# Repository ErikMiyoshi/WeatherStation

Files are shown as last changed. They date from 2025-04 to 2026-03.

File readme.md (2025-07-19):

# 💡 Multi-Domain Learning Project: Hardware, Firmware & Software

Welcome to this project that combines **hardware design**, **embedded firmware**, and **application-level software**. The project is a portable weather station that gets temperature, humidity, pressure and show on a dashboard.

## 🧭 Project Goal

This is a personal project for me to learning all aspects of an embedded system project that involves:

- 🔧 **Hardware**: Circuit design, schematics, and PCB development
- 🧠 **Firmware**: Embedded code for microcontrollers, in this case ESP32
- 💻 **Software**: Applications that interact with the device, including dashboards and data logging

The objective is to **understand how these layers connect**, and how to manage a multidisciplinary project effectively.

---

## 🗂 Repository Structure

WeatherStation/
├── HW/ # Schematics, PCB design files (KiCad, etc.)
├── FW/ # Embedded C/C++ code (e.g., ESP-IDF)
├── SW/ # Python, Flask, GUI application (e.g., dashboard)
├── docs/ # Documentation, diagrams, and learning notes
├── LICENSE
└── README.md

---

## 📌 What I'm learning

- Designing a hardware system using open-source tools
- Writing low-level embedded firmware to read sensors and communicate
- Creating software tools to visualize and log the collected data
- Managing a complete project in a clean and modular way

---

## 🛠 Tech Stack

| Layer | Technology |
|---|---|
| Hardware | KiCad, breadboards, ESP32, sensors|
| Firmware | C, C++, ESP-IDF, MQTT |
| Software | Python, Flask, MQTT, Chart.js |
| Tools | Git, VSCode, KiCad, esp-idf |

---

## 🤝 Contributing

This is a learning project. Contributions are welcome! Feel free to open issues, suggest improvements, or ask questions. The goal is to learn collaboratively.

I'm not the best at programming and this project is also for me to improve my ability in writing code.

## 📄 License

This project is licensed under the MIT License. See LICENSE for details.

## 🙋‍♂️ Author
Created by Erik as a personal journey to explore full-stack embedded systems.

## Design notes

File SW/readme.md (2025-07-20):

# 🖥️ Software - Dashboard and Backend

This folder contains the software layer of the project responsible for collecting, storing, and visualizing data from the embedded system. It includes a backend API (Flask or Django), a MySQL-compatible database (MariaDB), and a frontend dashboard using Chart.js.

---

## 🎯 Purpose

The software part is designed to:

- Receive sensor data from the firmware (e.g., via MQTT or HTTP)
- Store the data in a local database on a Raspberry Pi
- Expose a RESTful API to serve the data
- Display the data in an interactive dashboard using Chart.js

## 🧰 Tech Stack

| Layer | Technology |
|---|---|
| Backend | Flask or Django |
| Database | MariaDB (MySQL) |
| Frontend | HTML, CSS, JS |
| Charts | Chart.js |
| Hosting | Raspberry Pi |

---

## 🧱 Learning Focus
- How to set up a local backend with persistent storage

- Creating REST APIs for embedded data ingestion

- Using Chart.js to visualize real-time or historical data

- Deploying and maintaining applications on a Raspberry Pi

## 📄 License
This software is released under the MIT License.

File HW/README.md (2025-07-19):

# 🔧 Hardware Design for WeatherStation Project

This folder contains all the hardware-related files and documentation for the project focused on designing and building the physical electronic system.

## 🎯 Purpose

The hardware part of this project aims to develop the board that will be used:

- Basic circuit design principles
- Sensor interfacing and connections
- PCB design and layout using open-source tools
- Integration with embedded firmware on microcontrollers

---

## 📚 Learning Resources

- Basic electronics and circuit theory  
- How to read and create schematics  
- PCB design best practices  
- Hardware debugging tips

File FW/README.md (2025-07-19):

# ⚙️ Firmware for Learning Project

This folder contains the embedded firmware code that runs on the microcontroller, handling sensor data acquisition, device control, and communication with other systems.

---

## 🎯 Purpose

The firmware aims to provide hands-on experience with:

- Writing low-level code for microcontrollers (e.g., ESP32)
- Interfacing sensors and peripherals
- Managing communication protocols (e.g., MQTT, UART, I2C, SPI)
- Implementing power management and device states
- Organizing firmware code for maintainability and scalability

---

## 🛠 Development Environment

- **Platform:** ESP-IDF 
- **Languages:** C / C++  
- **Toolchain:** GCC-based toolchains, ESP-IDF tools
- **Flashing:** Using tools like `idf.py`, `esptool.py`, or vendor-specific utilities

---

I also have another repository [ESP32_Basic_Projects](https://github.com/ErikMiyoshi/ESP32_Basic_Projects) that I write basic examples with each submodule of the device (sensors, displays, wifi, etc.) to test each part individually

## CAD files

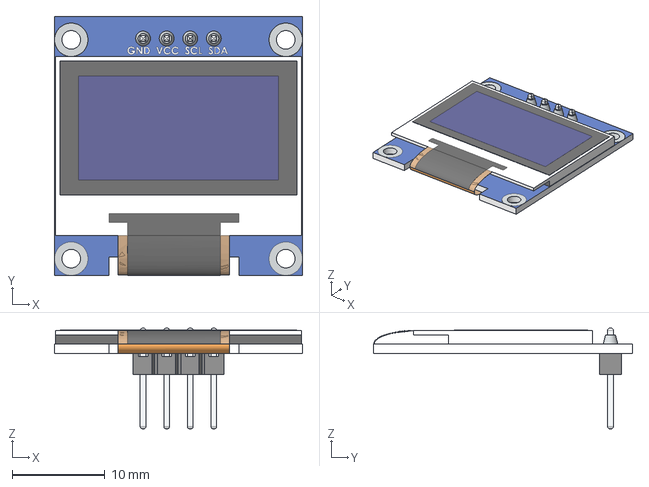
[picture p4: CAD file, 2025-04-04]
HW/3D_models/display-oled-ssd1306-de-0-96-1.snapshot.6/OLED-128x64-0.96.step
26.7 x 27.9 x 10.8 mm

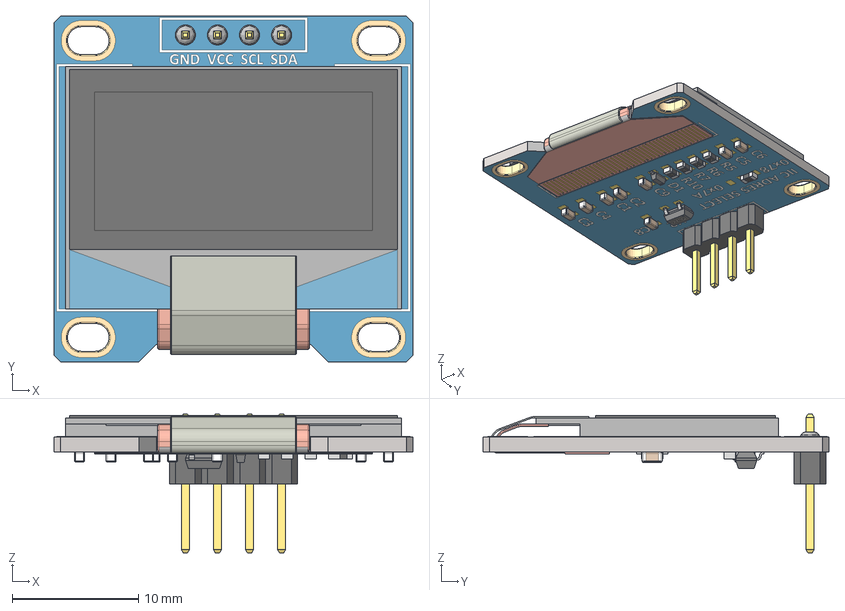
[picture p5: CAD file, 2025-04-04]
HW/3D_models/pantalla-oled-0-96-128x64-1.snapshot.7/Pantalla OLED 0.96'' 128x64.stp
28.4 x 27.4 x 11.0 mm
SOT-23_TOR
RES_CR16_MTK_1 x 4
RES_CR16_MTK
SOD323F_DIO

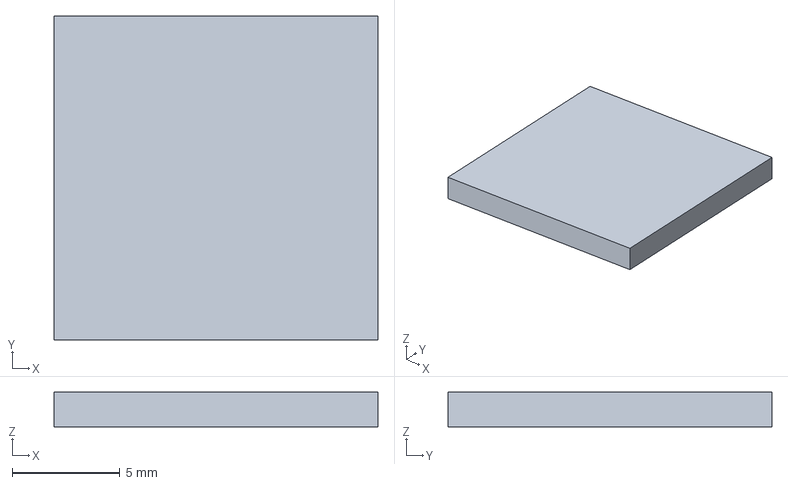
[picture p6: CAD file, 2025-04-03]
HW/Free_Cad_models/bmp280_aht20_base_board.FCStd
15.0 x 15.0 x 1.60 mm

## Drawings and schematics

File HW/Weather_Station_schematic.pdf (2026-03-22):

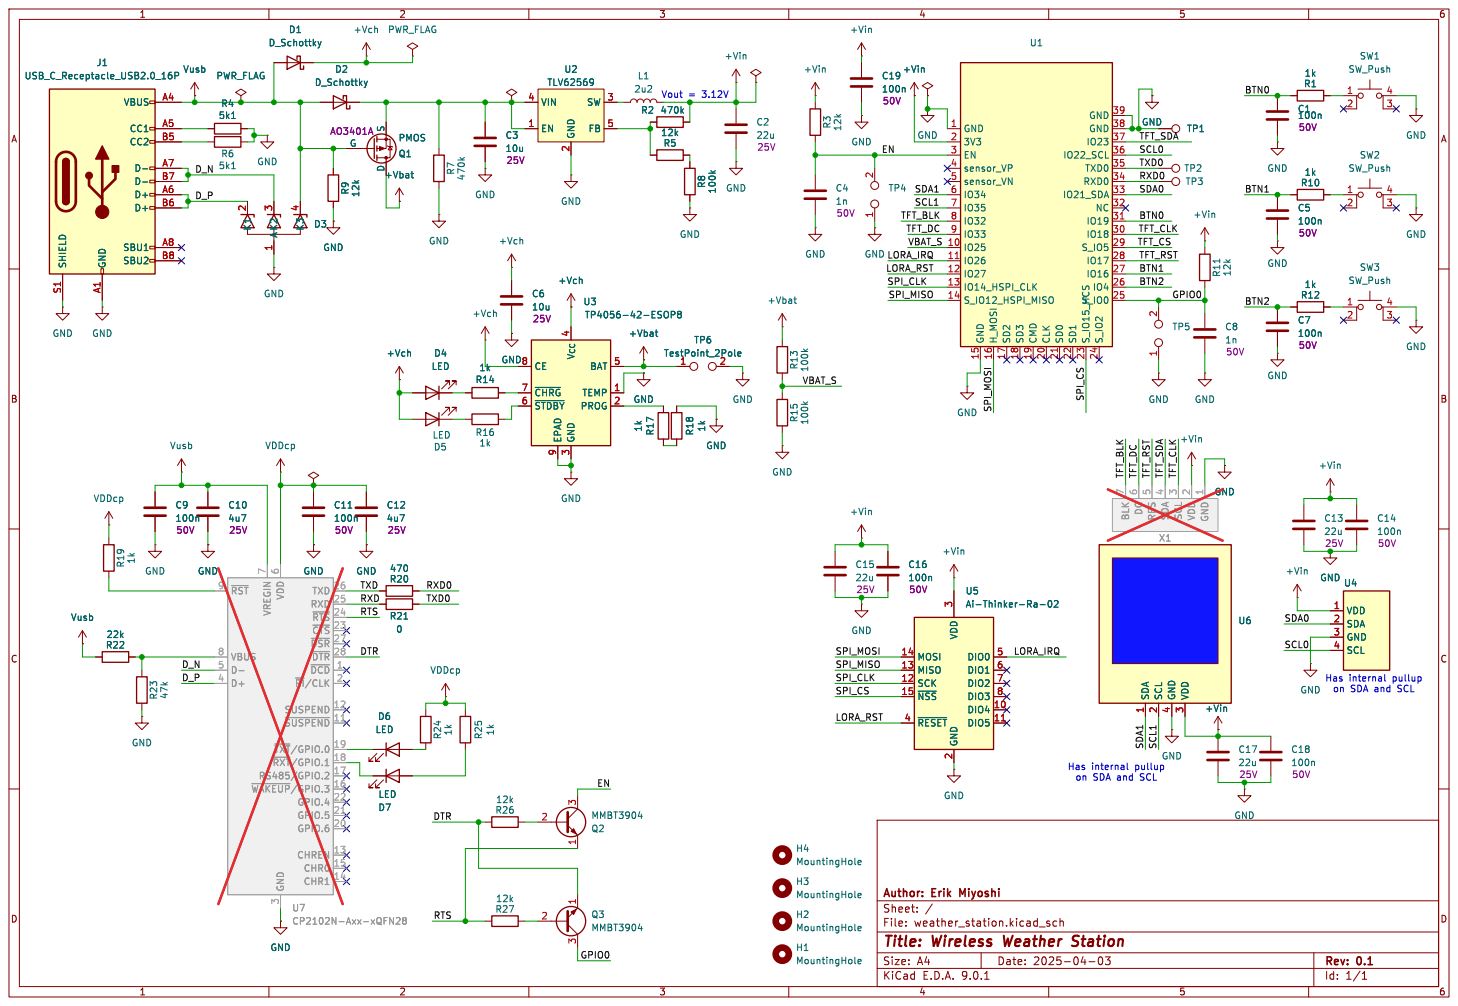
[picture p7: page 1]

GND U4VDD 1 SDA 2 GND 3 SCL 4 +VinGND

VDD 1 SDA 2 GND 3 SCL 4 U4 R19 1k

3 TXD 26 RXD 25 ~{RTS} 24 ~{CTS} 23 ~{DSR} 27 ~{DTR} 28 ~{DCD}1 ~{RI}/CLK2 SUSPEND 12 ~{SUSPEND}11 ~{TXT}/GPIO.019 ~{RXT}/GPIO.118 RS485/GPIO.2 17 ~{WAKEUP}/GPIO.316 GPIO.4 22 GPIO.5 21 GPIO.6 20 CHREN 13 CHR0 15 CHR1 14 U7 CP2102N-Axx-xQFN28

3 TXD 26 RXD 25 ~{RTS} 24 ~{CTS} 23 ~{DSR} 27 ~{DTR} 28 ~{DCD}1 ~{RI}/CLK2 SUSPEND 12 ~{SUSPEND}11 ~{TXT}/GPIO.019 ~{RXT}/GPIO.118 RS485/GPIO.2 17 ~{WAKEUP}/GPIO.316 GPIO.4 22 GPIO.5 21 GPIO.6 20 CHREN 13 CHR0 15 CHR1 14 D7

on SDA and SCL

H2 MountingHole H3 MountingHole H1 MountingHole H4 MountingHole

Id: 1/1 Title: Wireless Weather Station

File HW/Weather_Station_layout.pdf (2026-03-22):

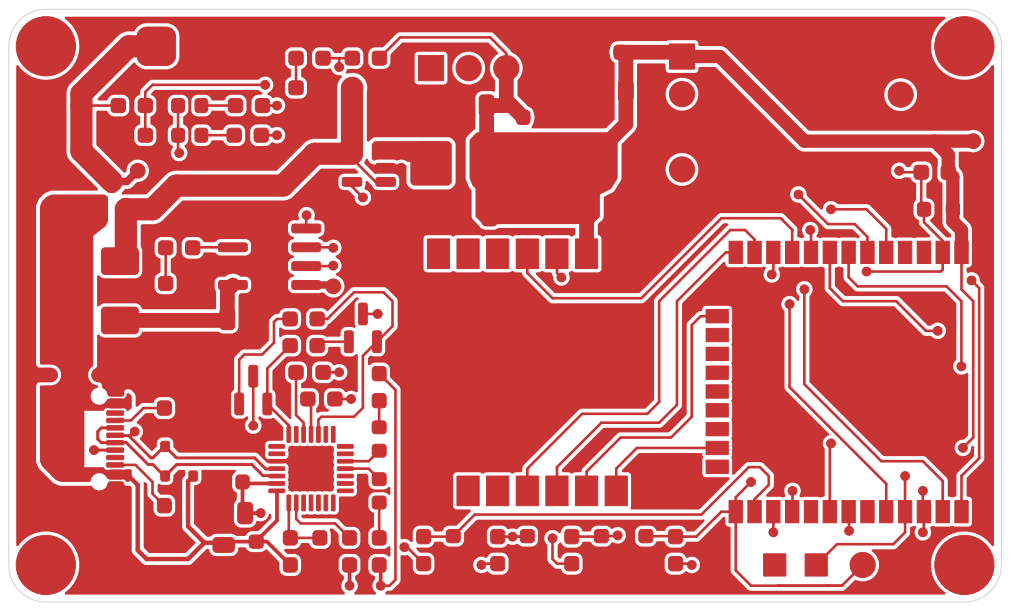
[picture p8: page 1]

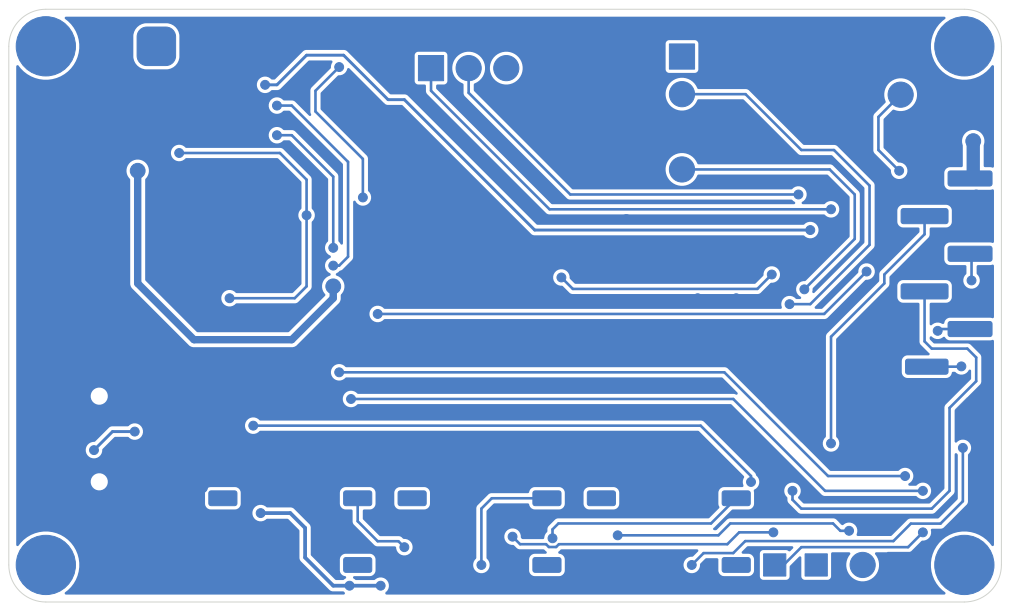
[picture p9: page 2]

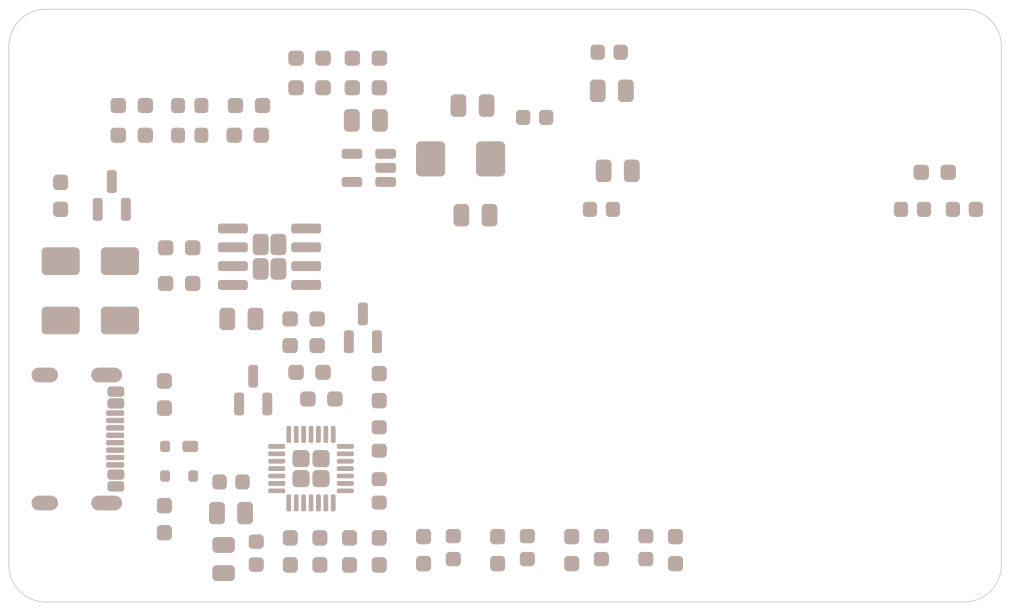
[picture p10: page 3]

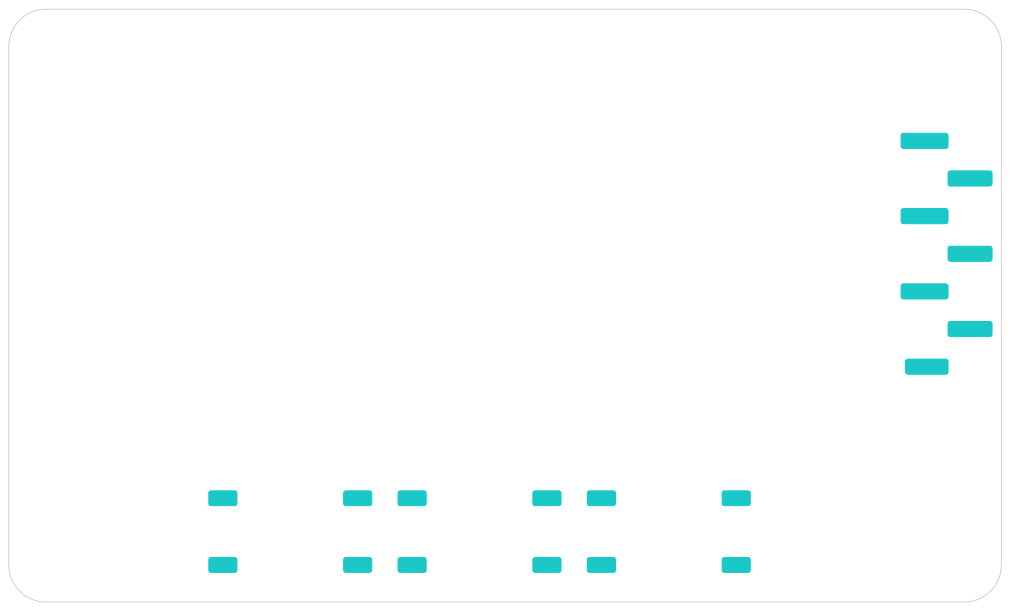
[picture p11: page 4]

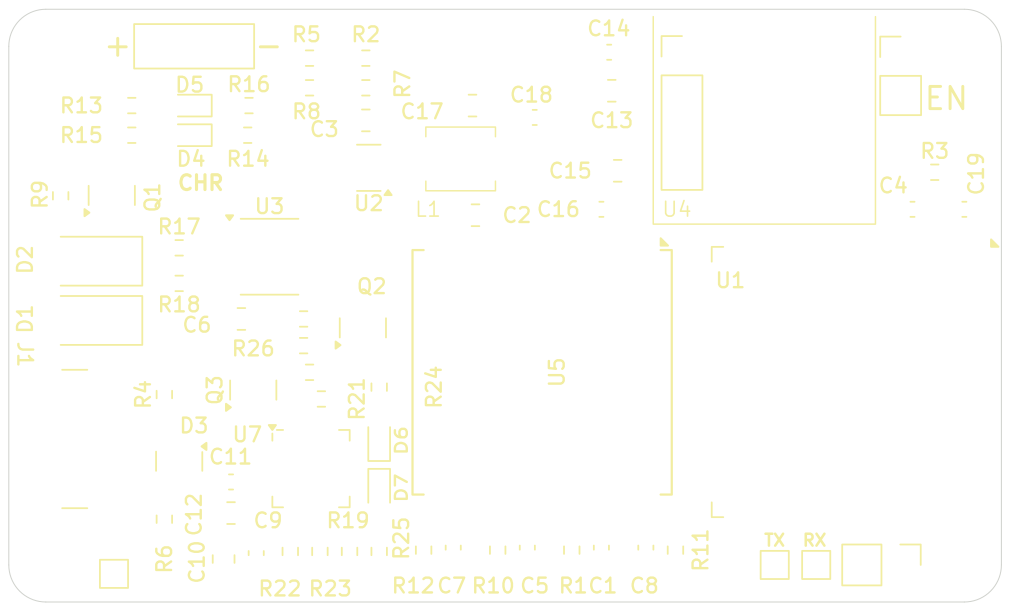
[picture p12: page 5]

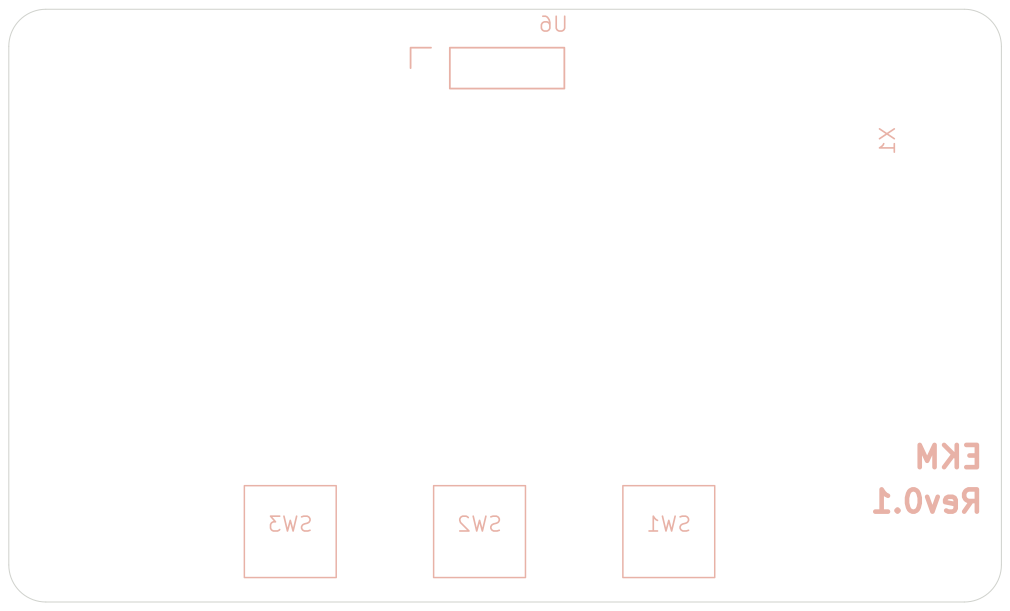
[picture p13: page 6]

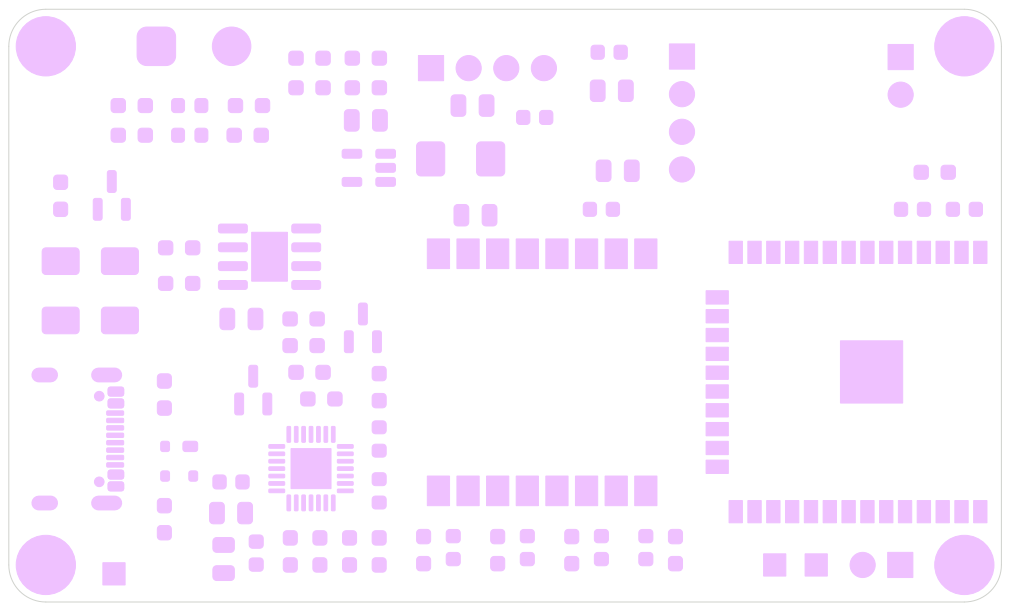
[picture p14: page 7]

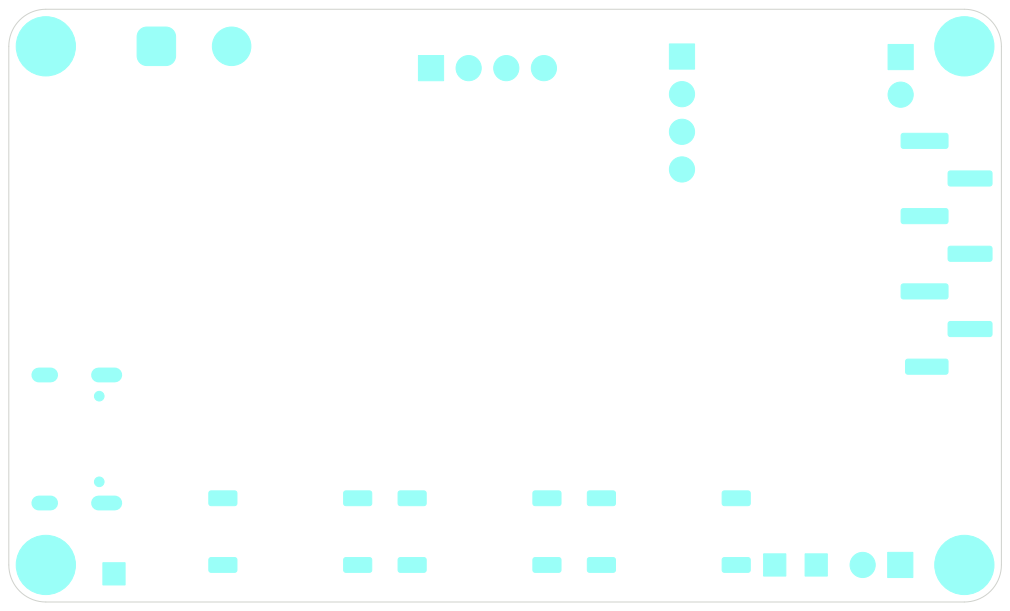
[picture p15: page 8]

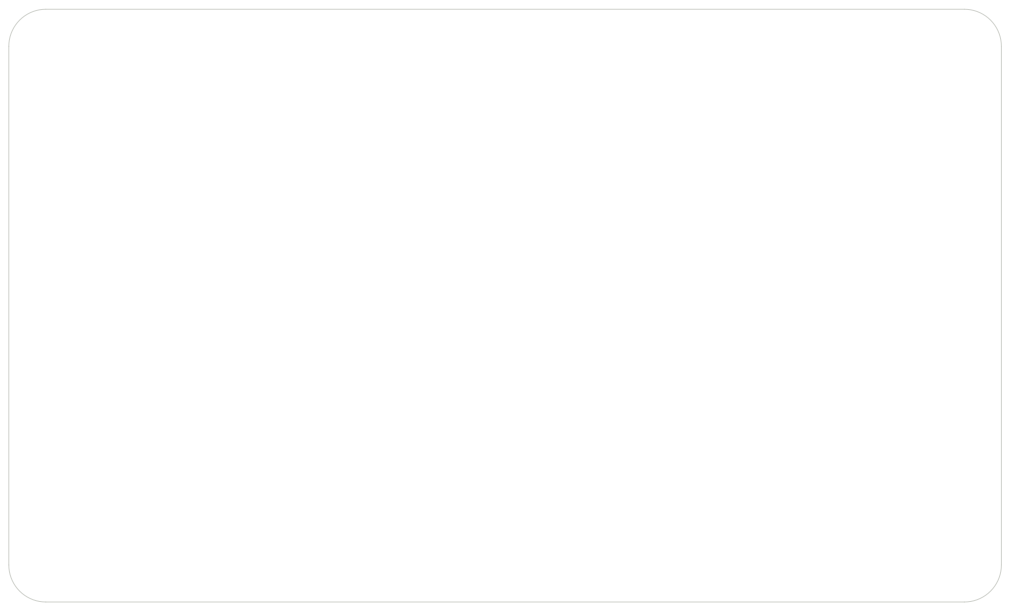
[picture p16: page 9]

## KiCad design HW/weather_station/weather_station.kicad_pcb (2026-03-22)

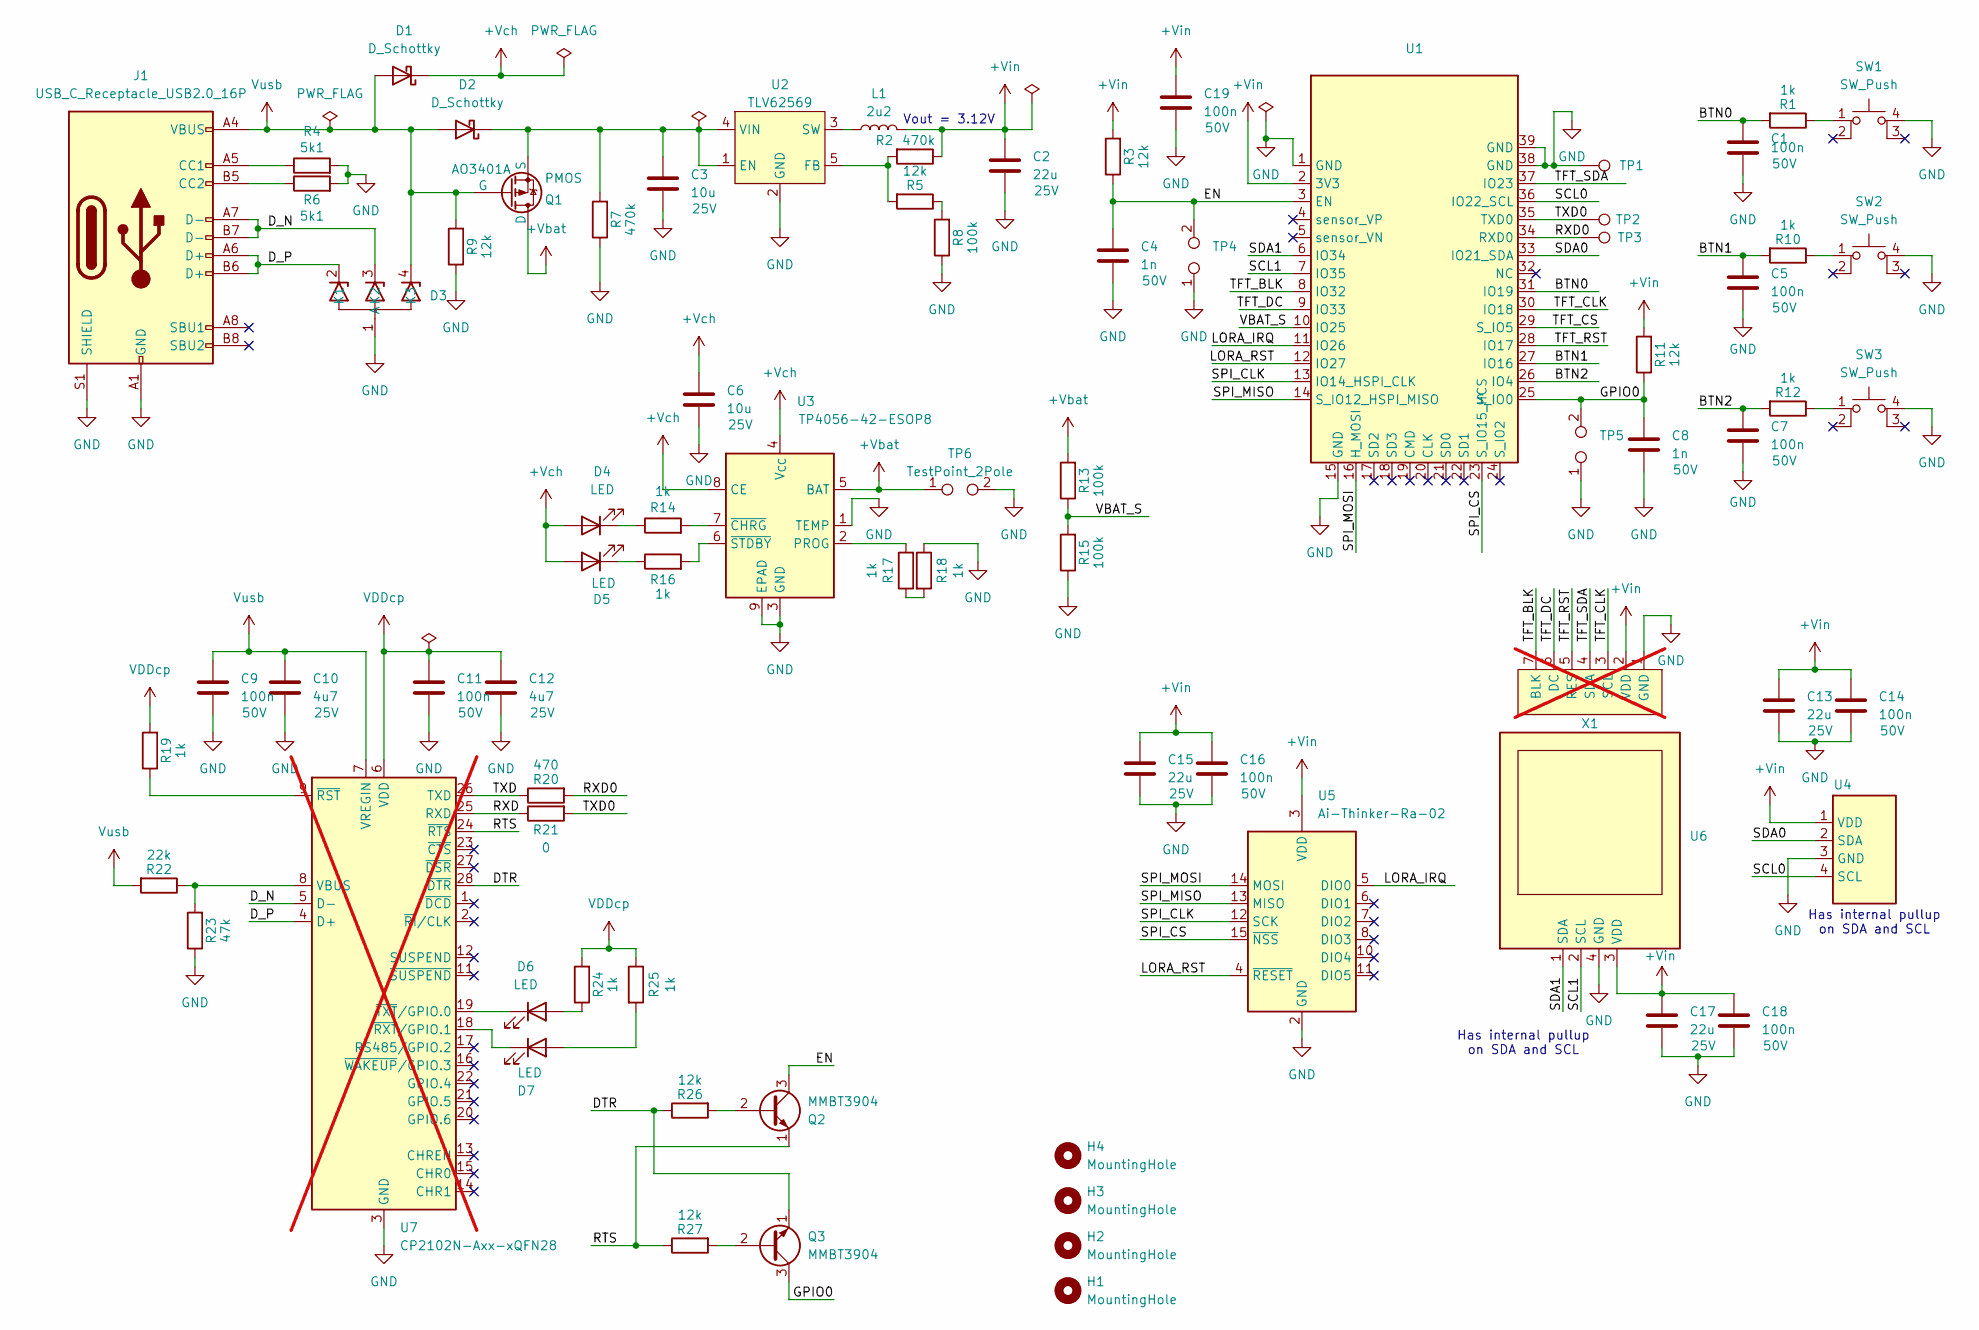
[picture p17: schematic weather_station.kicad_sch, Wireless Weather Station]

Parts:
C1, C5, C7, C9, C11, C14, C16, C18, C19: 100n; C_0603_1608Metric; Voltage 50V; LCSC Part # C14663
C2, C13, C15, C17: 22u; C_0805_2012Metric; Voltage 25V; LCSC Part # C45783
C3, C6: 10u; C_0805_2012Metric; Voltage 25V; LCSC Part # C15850
C4, C8: 1n; C_0603_1608Metric; Voltage 50V; LCSC Part # C1588
C10, C12: 4u7; C_0805_2012Metric; Voltage 25V; LCSC Part # C1779
D1, D2: D_Schottky; D_SMA; LCSC Part # C2480
D3: SOT-143; LCSC Part # C3040626
D4, D5, D6, D7: LED; LED_0603_1608Metric; LCSC Part # C2286
H1, H2, H3, H4: MountingHole; mounting_hole_2
J1: USB_C_Receptacle_USB2.0_16P; USB_C_Receptacle_GCT_USB4105-xx-A_16P_TopMnt_Horizontal_fix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; LCSC Part # C2765186
L1: 2u2; Inductor_4.5x4.1x2; LCSC Part # C22463806
Q1: PMOS; SOT-23_(pins_inverted); LCSC Part # C15127
Q2, Q3: MMBT3904; SOT-23_(pins_12_inverted); LCSC Part # C20526
R1, R10, R12, R14, R16, R17, R18, R19, R24, R25: 1k; R_0603_1608Metric_Pad0.98x0.95mm_HandSolder; LCSC Part # C21190
R2, R7: 470k; R_0603_1608Metric_Pad0.98x0.95mm_HandSolder; LCSC Part # C23178
R3, R5, R9, R11, R26, R27: 12k; R_0603_1608Metric_Pad0.98x0.95mm_HandSolder; LCSC Part # C22790
R4, R6: 5k1; R_0603_1608Metric_Pad0.98x0.95mm_HandSolder; LCSC Part # C23186
R8, R13, R15: 100k; R_0603_1608Metric_Pad0.98x0.95mm_HandSolder; LCSC Part # C25803
R20: 470; R_0603_1608Metric_Pad0.98x0.95mm_HandSolder; LCSC Part # C23179
R21: 0; R_0603_1608Metric_Pad0.98x0.95mm_HandSolder; LCSC Part # C21189
R22: 22k; R_0603_1608Metric_Pad0.98x0.95mm_HandSolder; LCSC Part # C31850
R23: 47k; R_0603_1608Metric_Pad0.98x0.95mm_HandSolder; LCSC Part # C25819
SW1, SW2, SW3: SW_Push; tactile_switch_6x6; LCSC Part # C455110
TP1, TP2, TP3: TestPoint; TestPoint_THTPad_1.5x1.5mm_Drill0.7mm
TP4, TP5: TestPoint_2Pole; PinHeader_1x02_P2.54mm_Vertical
TP6: TestPoint_2Pole; TestPoint_2Pads_Pitch5.08mm_Drill1.3mm
U1: ESP32-WROOM-32 or ESP32S_no_paste
U2: TLV62569; SOT-23-5; LCSC Part # C141836
U3: TP4056-42-ESOP8; SOIC-8-1EP_3.9x4.9mm_P1.27mm_EP2.41x3.3mm_ThermalVias_via_0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; LCSC Part # C725790
U4: BMP280_AHT20
U5: Ai-Thinker-Ra-02; Ai-Thinker-Ra-01-LoRa_no_paste
U6: 0.96inch_lcd
U7: CP2102N-Axx-xQFN28; QFN-28-1EP_5x5mm_P0.5mm_EP2.7x2.7mm_ThermalVias_via_0.3mm; not fitted
X1: Header_7x2.54_smt; not fitted

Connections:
+Vbat: Q1.1 (D), R13.2, TP6.1, U3.5 (BAT)
+Vch: C6.1, D1.1 (K), D4.2 (A), D5.2 (A), U3.4 (V_{CC}), U3.8 (CE)
+Vin: C2.1, C13.1, C14.1, C15.1, C16.1, C17.1, C18.1, C19.1, L1.2, R2.1, R3.2, R11.2, U1.2 (3V3), U4.1 (VDD), U5.3 (VDD), U6.3 (VDD), X1.2 (VDD)
/BTN0: C1.1, R1.2, U1.31 (IO19)
/BTN1: C5.1, R10.2, U1.27 (IO16)
/BTN2: C7.1, R12.2, U1.26 (IO4)
/DTR: Q3.1 (E), R26.1, U7.28 (~DTR)
/D_N: D3.3 (K2), J1.A7 (D-), J1.B7 (D-), U7.5 (D-)
/D_P: D3.2 (K1), J1.A6 (D+), J1.B6 (D+), U7.4 (D+)
/EN: C4.1, Q2.3 (C), R3.1, TP4.2, U1.3 (EN)
/GPIO0: C8.1, Q3.3 (C), R11.1, TP5.2, U1.25 (S_IO0)
/LORA_IRQ: U1.11 (IO26), U5.5 (DIO0)
/LORA_RST: U1.12 (IO27), U5.4 (~RESET)
/RTS: Q2.1 (E), R27.1, U7.24 (~RTS)
/RXD: R21.1, U7.25 (RXD)
/RXD0: R20.2, TP3.1, U1.34 (RXD0)
/SCL0: U1.36 (IO22_SCL), U4.4 (SCL)
/SCL1: U1.7 (IO35), U6.2 (SCL)
/SDA0: U1.33 (IO21_SDA), U4.2 (SDA)
/SDA1: U1.6 (IO34), U6.1 (SDA)
/SPI_CLK: U1.13 (IO14_HSPI_CLK), U5.12 (SCK)
/SPI_CS: U1.23 (S_IO15_HCS), U5.15 (~NSS)
/SPI_MISO: U1.14 (S_IO12_HSPI_MISO), U5.13 (MISO)
/SPI_MOSI: U1.16 (H_MOSI), U5.14 (MOSI)
/TFT_BLK: U1.8 (IO32), X1.7 (BLK)
/TFT_CLK: U1.30 (IO18), X1.3 (SCL)
/TFT_CS: U1.29 (S_IO5)
/TFT_DC: U1.9 (IO33), X1.6 (DC)
/TFT_RST: U1.28 (IO17), X1.5 (RES)
/TFT_SDA: U1.37 (IO23), X1.4 (SDA)
/TXD: R20.1, U7.26 (TXD)
/TXD0: R21.2, TP2.1, U1.35 (TXD0)
/VBAT_S: R13.1, R15.2, U1.10 (IO25)
GND: C1.2, C2.2, C3.2, C4.2, C5.2, C6.2, C7.2, C8.2, C9.2, C10.2, C11.2, C12.2, C13.2, C14.2, C15.2, C16.2, C17.2, C18.2, C19.2, D3.1 (A), J1.A1 (GND), J1.A12 (GND), J1.B1 (GND), J1.B12 (GND), J1.S1 (SHIELD), R4.2, R6.2, R7.1, R8.1, R9.1, R15.1, R18.1, R23.1, SW1.4 (A), SW2.4 (A), SW3.4 (A), TP1.1, TP4.1, TP5.1, TP6.2, U1.1 (GND), U1.15 (GND), U1.38 (GND), U1.39 (GND), U2.2 (GND), U3.1 (TEMP), U3.3 (GND), U3.9 (EPAD), U4.3 (GND), U5.1 (GND), U5.2 (GND), U5.9 (GND), U5.16 (GND), U6.4 (GND), U7.3 (GND), U7.29 (GND), X1.1 (GND)
unnamed: C3.1, D2.1 (K), Q1.3 (S), R7.2, U2.1 (EN), U2.4 (VIN)
unnamed: D4.1 (K), R14.1
unnamed: D5.1 (K), R16.1
unnamed: D6.2 (A), R24.1
unnamed: D6.1 (K), U7.19 (~TXT/GPIO.0)
unnamed: D7.2 (A), R25.2
unnamed: D7.1 (K), U7.18 (~RXT/GPIO.1)
unnamed: J1.A5 (CC1), R4.1
unnamed: J1.B5 (CC2), R6.1
unnamed: Q2.2 (B), R26.2
unnamed: Q3.2 (B), R27.2
unnamed: R1.1, SW1.1
unnamed: R5.1, R8.2
unnamed: R10.1, SW2.1
unnamed: R12.1, SW3.1
unnamed: R17.1, R18.2
unnamed: R2.2, R5.2, U2.5 (FB)
unnamed: L1.1, U2.3 (SW)
unnamed: R17.2, U3.2 (PROG)
unnamed: R14.2, U3.7 (~CHRG)
unnamed: R16.2, U3.6 (~STDBY)
unnamed: R22.1, R23.2, U7.8 (VBUS)
unnamed: R19.1, U7.9 (~RST)
VDDcp: C11.1, C12.1, R19.2, R24.2, R25.1, U7.6 (VDD)
Vusb: C9.1, C10.1, D1.2 (A), D2.2 (A), D3.4 (K3), J1.A4 (VBUS), J1.A9 (VBUS), J1.B4 (VBUS), J1.B9 (VBUS), Q1.2 (G), R9.2, R22.2, U7.7 (VREGIN)

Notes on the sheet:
Has internal pullup on SDA and SCL
Vout = 3.12V

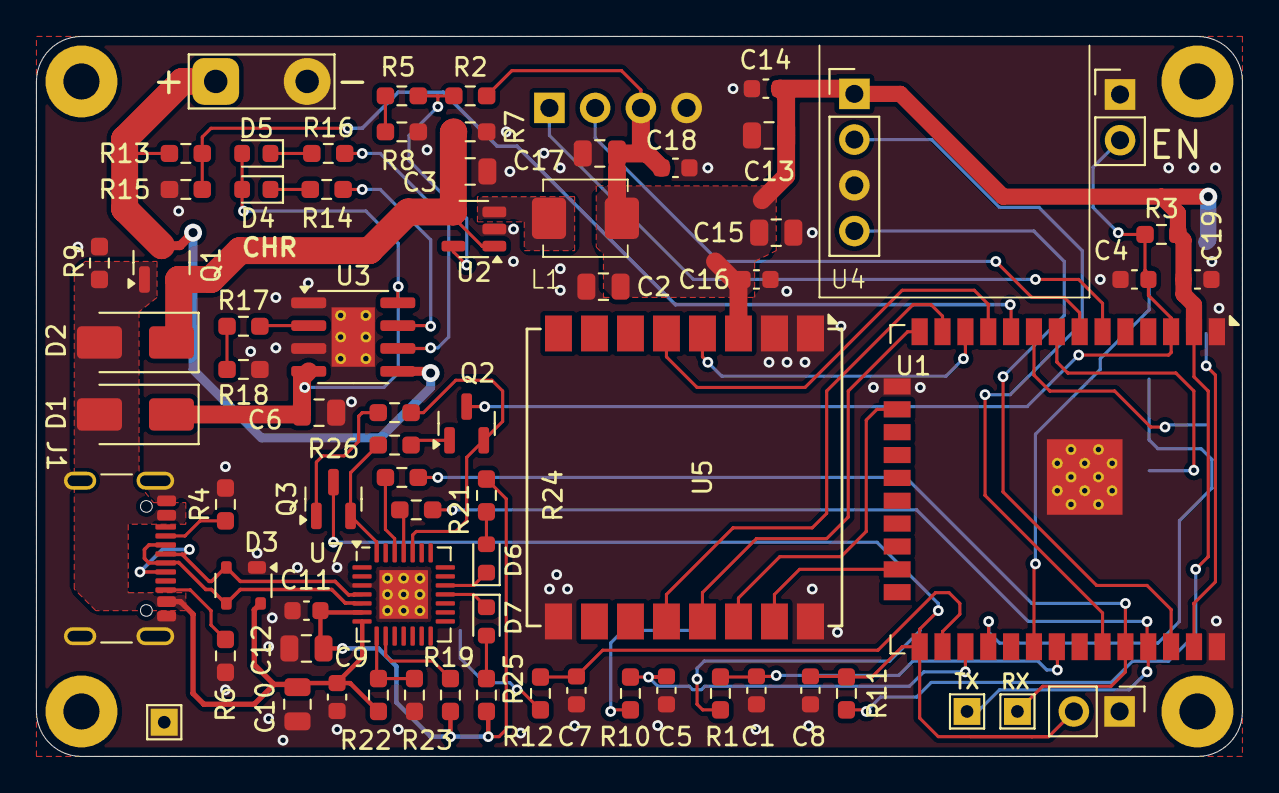
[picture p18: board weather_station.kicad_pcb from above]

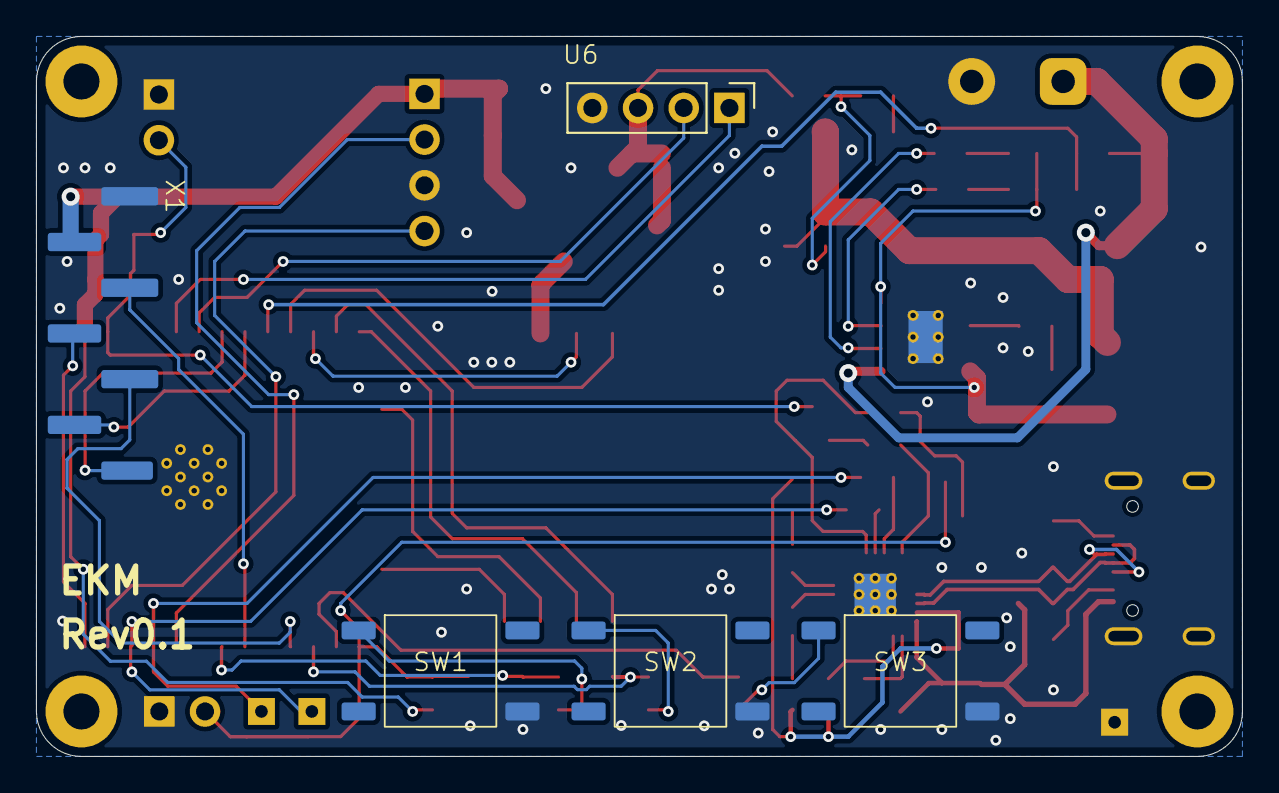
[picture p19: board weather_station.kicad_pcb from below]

Board: 2 copper layers, 67.0 x 40.0 mm, 79 parts (5 on the bottom side), 58 nets.

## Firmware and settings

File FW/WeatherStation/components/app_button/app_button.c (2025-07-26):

#include <stdio.h>
#include <string.h>
#include <esp_log.h>
#include "freertos/FreeRTOS.h"

#include "esp_adc/adc_oneshot.h"
#include "esp_adc/adc_continuous.h"
#include "esp_adc/adc_cali.h"
#include "esp_adc/adc_cali_scheme.h"

#include "driver/gpio.h"

#include "app_button.h"

#define EXAMPLE_READ_LEN 4*128

static const char *TAG = "ADC";

static TaskHandle_t s_task_handle;

#define ADC_UNIT        ADC_UNIT_1
#define ADC_BITWIDTH    ADC_BITWIDTH_12
#define ADC_ATTEN_DB    ADC_ATTEN_DB_12

adc_oneshot_unit_handle_t adc1_handle = NULL;
adc_continuous_handle_t adc_handle = NULL;
adc_cali_handle_t adc_cali_handle = NULL;

int v_joystick;
int vbattery;
int buttonLeft = 1;
int buttonCenter = 1;
int buttonRight = 1;

static int adc_raw[2][10];
static int voltage[2][10];

bool is_button_left_pressed(void) {
    return !buttonLeft;
}

bool is_button_center_pressed(void) {
    return !buttonCenter;
}

bool is_button_right_pressed(void) {
    return !buttonRight;
}

int battery_get_voltage(void) {
    return vbattery;
}

bool is_joystick_pressed_right(void) {
    if(v_joystick > 3000) {
        return true;
    }
    return false;
}

bool is_joystick_pressed_left(void) {
    if(v_joystick < 200) {
        return true;
    }
    return false;
}

static void gpio_isr_handler(void* arg) {
    uint32_t gpio_num = (uint32_t) arg;
    if(gpio_num == GPIO_NUM_19) {
        buttonLeft = gpio_get_level(gpio_num);
    }
    if(gpio_num == GPIO_NUM_16) {
        buttonCenter = gpio_get_level(gpio_num);
    }
    if(gpio_num == GPIO_NUM_4) {
        buttonRight = gpio_get_level(gpio_num);
    }
}

static void button_gpio_init(void) {
    gpio_config_t cfg = {};
    cfg.intr_type = GPIO_INTR_ANYEDGE;
    cfg.mode = GPIO_MODE_INPUT;
    cfg.pull_up_en = GPIO_PULLUP_ENABLE;
    cfg.pin_bit_mask = (1ULL << GPIO_NUM_19) | (1ULL << GPIO_NUM_16) | (1ULL << GPIO_NUM_4) ;
    ESP_ERROR_CHECK(gpio_config(&cfg));
    
    gpio_install_isr_service(0);
    gpio_isr_handler_add(GPIO_NUM_19, gpio_isr_handler, (void *) GPIO_NUM_19);
    gpio_isr_handler_add(GPIO_NUM_16, gpio_isr_handler, (void *) GPIO_NUM_16);
    gpio_isr_handler_add(GPIO_NUM_4, gpio_isr_handler, (void *) GPIO_NUM_4);
}

int adc_get_single(void) {
    ESP_ERROR_CHECK(adc_oneshot_read(adc1_handle, ADC_CHANNEL_0, &adc_raw[0][0]));
    ESP_LOGI(TAG, "ADC%d Channel[%d] Raw Data: %d", ADC_UNIT_1 + 1, ADC_CHANNEL_0, adc_raw[0][0]);
    ESP_ERROR_CHECK(adc_cali_raw_to_voltage(adc_cali_handle, adc_raw[0][0], &voltage[0][0]));
    ESP_LOGI(TAG, "ADC%d Channel[%d] Cali Voltage: %d mV", ADC_UNIT_1 + 1, ADC_CHANNEL_0, voltage[0][0]);
    return voltage[0][0];
}

void adc_single_init(void) {
    adc_oneshot_unit_init_cfg_t init_config1 = {
        .unit_id = ADC_UNIT_1,
    };
    ESP_ERROR_CHECK(adc_oneshot_new_unit(&init_config1, &adc1_handle));

    adc_oneshot_chan_cfg_t config = {
        .atten = ADC_ATTEN_DB_12,
        .bitwidth = ADC_BITWIDTH_12,
    };

    ESP_ERROR_CHECK(adc_oneshot_config_channel(adc1_handle, ADC_CHANNEL_0, &config));
}


static bool adc_conv_done(adc_continuous_handle_t handle, const adc_continuous_evt_data_t *edata, void *user_data) {
    BaseType_t mustYield = pdFALSE;
    vTaskNotifyGiveFromISR(s_task_handle, &mustYield);
    return (mustYield == pdTRUE);
}

static void adc_task(void *args) {
    esp_err_t ret;
    uint32_t ret_num = 0;
    uint8_t result[EXAMPLE_READ_LEN] = {0};
    
    while(1) {
        ulTaskNotifyTake(pdTRUE, portMAX_DELAY);
        ret = adc_continuous_read(adc_handle, result, EXAMPLE_READ_LEN, &ret_num, 0);
        if (ret == ESP_OK) {
            for (int i = 0; i < 5/*ret_num*/; i += SOC_ADC_DIGI_RESULT_BYTES) {
                adc_digi_output_data_t *p = (adc_digi_output_data_t*)&result[i];
                uint32_t chan_num = p->type1.channel;
                uint32_t data = p->type1.data;
                /* Check the channel number validation, the data is invalid if the channel num exceed the maximum channel */
                if (chan_num < SOC_ADC_CHANNEL_NUM(ADC_UNIT)) {
                    adc_cali_raw_to_voltage(adc_cali_handle,data, &vbattery);
                    // if(chan_num == 0) {
                    // ESP_LOGI(TAG, "C: %"PRIu32", V: %"PRIx32", Cali: %d", chan_num, data, v_joystick);
                    // }
                    //ESP_LOGI(TAG, "Unit: %d, Channel: %"PRIu32", Value: %"PRIx32, ADC_UNIT, chan_num, data);
                } else {
                    ESP_LOGW(TAG, "Invalid data");
                }
            }
            vTaskDelay(50 / portTICK_PERIOD_MS);
        } else if (ret == ESP_ERR_TIMEOUT) {
            //We try to read `EXAMPLE_READ_LEN` until API returns timeout, which means there's no available data
            break;
        }
    }
}

static void calibrate_adc(adc_cali_handle_t *out_handle) {
    adc_cali_scheme_ver_t cali_scheme;
    adc_cali_handle_t cali_handle = NULL;
    bool calibrated = false;
    esp_err_t ret;

    ESP_ERROR_CHECK(adc_cali_check_scheme(&cali_scheme));

    if(cali_scheme & 1) {
        ESP_LOGI(TAG, "Suport ADC_CALI_SCHEME_VER_LINE_FITTING");
    }
    if(cali_scheme & 2) {
        ESP_LOGI(TAG, "Suport ADC_CALI_SCHEME_VER_CURVE_FITTING");
    }
    
    if(!calibrated) {
        ESP_LOGI(TAG, "Calibrating ADC...");
        adc_cali_line_fitting_config_t cali_cfg = {
            .unit_id = ADC_UNIT,
            .atten = ADC_ATTEN_DB,
            .bitwidth = ADC_BITWIDTH,
        };

        ret = adc_cali_create_scheme_line_fitting(&cali_cfg, &cali_handle);
    }
    
    *out_handle = cali_handle;

    if (ret == ESP_OK) {
        ESP_LOGI(TAG, "Calibration Success");
    } else if (ret == ESP_ERR_NOT_SUPPORTED || !calibrated) {
        ESP_LOGW(TAG, "eFuse not burnt, skip software calibration");
    } else {
        ESP_LOGE(TAG, "Invalid arg or no memory");
    }
}
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

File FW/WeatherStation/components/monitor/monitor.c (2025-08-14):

#include "esp_log.h"
#include "freertos/FreeRTOS.h"
#include "aht20_bmp280.h"
#include "oled_ui.h"
#include "app_button.h"
#include "menu.h"
#include "esp_timer.h"
#include "esp_sleep.h"
#include "mqtt_app.h"

#define DEVICE_NUM 2

static const char *TAG = "monitor";

typedef struct sensors_queue {
    QueueHandle_t queue_aht20;
    QueueHandle_t queue_bmp280;
} sensors_queue;

typedef struct sensors_data_t {
    aht20_measure aht20_data;
    bmp280_measure bmp280_data;
} sensors_data_t;

struct sensors_queue queues;
sensors_data_t sensors_data;

void monitor_task(void *arg) {
    uint8_t batteryOperated = (int)arg;
    uint64_t time;
    time = esp_timer_get_time();
    int deviceNum = DEVICE_NUM;

    uint8_t messageSent = 0; //bit 0 -> aht20
                             //bit 1 -> bmp280
                             //bit 2 -> adc battery
    while(1) {
        //ESP_LOGI(TAG,"Monitor Task");
        if(esp_timer_get_time() - time > 10000000) {
            time = esp_timer_get_time();
            ESP_LOGI(TAG,"Turn display off");
            //lv_turn_off();
        }
        if(xQueueReceive(queues.queue_aht20, &sensors_data.aht20_data, 0)) {
            ESP_LOGI(TAG,"Received data from queue AHT20");
            
            char payload[100];
            snprintf(payload, sizeof(payload), "{\"device\":%d, \"sensor\": \"aht20\", \"t\":%.2f, \"h\":%.2f}", deviceNum, sensors_data.aht20_data.aht20_temperature, sensors_data.aht20_data.aht20_humidity);
            if(mqtt_send_message("measure/", payload) > 0)
                messageSent |= 1;
            lv_set_sensors_value(sensors_data.aht20_data.aht20_temperature,sensors_data.aht20_data.aht20_humidity);
        }
        if(xQueueReceive(queues.queue_bmp280, &sensors_data.bmp280_data, 0)) {
            ESP_LOGI(TAG,"Received data from queue BMP280");
            char payload[100];
            snprintf(payload, sizeof(payload), "{\"device\":%d, \"sensor\": \"bmp280\", \"t\":%.2f, \"p\":%.2f}", deviceNum, sensors_data.bmp280_data.bmp280_temperature, sensors_data.bmp280_data.bmp280_pressure);
            if(mqtt_send_message("measure/", payload) > 0)
                messageSent |= (1 << 1);
        }
        //lv_set_battery_value(battery_get_voltage());
        if(is_button_center_pressed()) {
            ESP_LOGI(TAG,"Button center pressed");
            //menu_handle_input(0,0,1);
            time = esp_timer_get_time();
        }
        if(is_button_left_pressed()) {
            ESP_LOGI(TAG,"Button left pressed");
            //menu_handle_input(1,0,0);
            time = esp_timer_get_time();
        }
        if(is_button_right_pressed()) {
            ESP_LOGI(TAG,"Button right pressed");
            //menu_handle_input(0,1,0);
            time = esp_timer_get_time();
        }
        if(batteryOperated && ((messageSent >> 2) & 1) == 0) {
            int bVoltage = adc_get_single();
            ESP_LOGI(TAG,"ADC reading: %dV", adc_get_single());
            char payload[100];
            snprintf(payload, sizeof(payload), "{\"device\":%d, \"sensor\": \"battery\", \"v\":%d}", deviceNum, 2*bVoltage);
            mqtt_send_message("measure/", payload);
            messageSent |= 1 << 2;
        }
        printf("messageSent: %d", messageSent);
        if(messageSent == 0b111 || (!batteryOperated && messageSent == 0b011)) {
            ESP_LOGI(TAG,"All messages were sent\n");
            const int wakeup_time_sec = 10*60;
            printf("Enabling timer wakeup, %ds\n", wakeup_time_sec);
            ESP_ERROR_CHECK(esp_sleep_enable_timer_wakeup(wakeup_time_sec * 1000000));
            vTaskDelay(1000 / portTICK_PERIOD_MS);
            esp_deep_sleep_start();
            //Todo, enter in sleep mode for 10minutes
        }
        vTaskDelay(100 / portTICK_PERIOD_MS);
        //menu_handle_input(0,0,0);
    }
}

void monitor_init(QueueHandle_t queue_aht20, QueueHandle_t queue_bmp280, int batOp) {
    queues.queue_aht20 = queue_aht20;
    queues.queue_bmp280 = queue_bmp280;

    xTaskCreate(monitor_task, "monitor_task", 4096, (void *)batOp, 1, NULL);
}

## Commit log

2025-04-03 Initial circuit - USBC, CP2102, ESP32
    [bmp280_aht20_base_board-Body.step, bmp280_aht20_base_board.FCStd, weather_station.kicad_pcb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]
2025-04-04 Schematic done, Layout in progress
    [OLED-128x64-0.96.step, Pantalla OLED 0.96'' 128x64.stp, bmp280_aht20_base_board-Body.step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]
2025-04-06 Adjusting components
    [weather_station.kicad_pcb, weather_station.kicad_sch]
2025-04-07 Adjust min via hole size to 0.3mm
    [weather_station.kicad_pcb, weather_station.kicad_sch]
2025-04-08 Revision for production
    [weather_station.kicad_pcb]
2025-06-08 Adjusting folders and separate firmware and hardware
    [OLED-128x64-0.96.step, Pantalla OLED 0.96'' 128x64.stp, bmp280_aht20_base_board-Body.step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]
2025-06-09 add functions to read aht20 sensor
2025-06-15 add a queue and monitor to share data between sensors and display
2025-06-15 add sntp
    [partitions.csv]
2025-06-16 add a basic menu to display on oled screen, using a joystick hw-504 to select options (for tests only, in future will be used 3 push buttons)
2025-07-08 Add battery voltage monitor
2025-07-26 Add nvs code to store a variable to indicate if a device is battery operated
2025-07-26 Change ADC to one shot, disable display, enable deepsleep
2025-07-26 Add options to select which sensor will be shown on chart
2025-08-14 Fix code to send battery voltage only one time
    [monitor.c]
2026-03-22 Generating pdf files for hw
    [weather_station.kicad_pcb, weather_station.kicad_sch]
